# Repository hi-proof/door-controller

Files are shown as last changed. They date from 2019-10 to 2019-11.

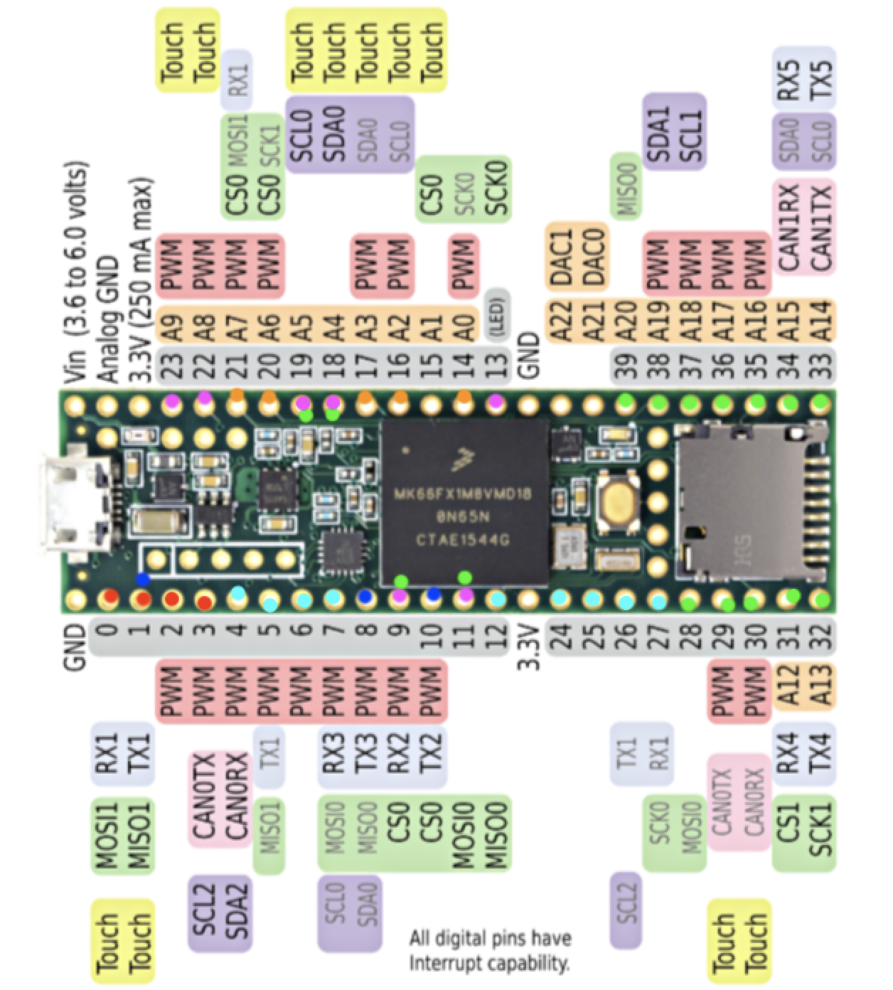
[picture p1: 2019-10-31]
pinout.png

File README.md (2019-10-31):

# Teensy 3.6 pinout

(see pinout.png)

* Red - b2b / serial (2 of the pins need to be serial TX/RX)
* Blue - LED ws2812 (pins need to be unused serial TX, should be limited to serial 1, 2, or 3)
* Pink - Audio - see audio shield docs. these can't be changed
* Orange - PWM
* Green - Door controllers
* Aqua - IO Panel

Notes:

1. 4 pins overlap between audio & door controller - those are for door controller D which can't be used at the same time as audio shield

2. Pin 15 is free and can be used for board id pull up / pull down

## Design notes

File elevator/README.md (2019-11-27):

Remember to change TeensyStep to use a different timer that doesn't conflict with PWM pins!!!

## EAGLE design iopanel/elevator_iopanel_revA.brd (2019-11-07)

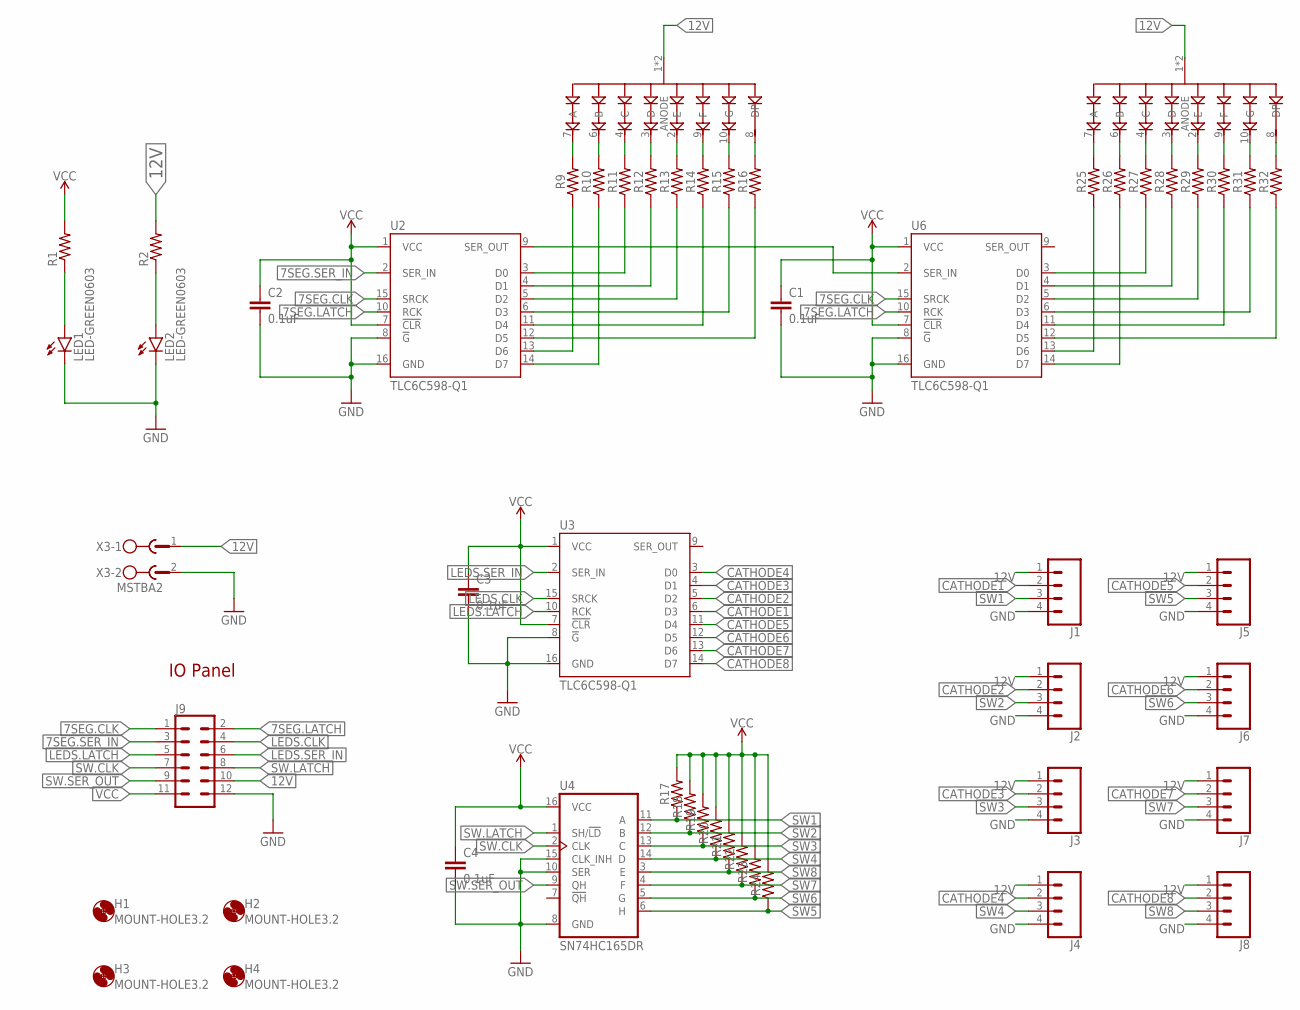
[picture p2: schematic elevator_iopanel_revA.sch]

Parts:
C1, C2, C3, C4: 0.1uF; 0603
D2, D4: SA15-11EWA
H1, H2, H3, H4: MOUNT-HOLE3.2; 3,2
J1, J2, J3, J4, J5, J6, J7, J8: CONN_04LONGPADS; 1X04_LONGPADS
J9: CONN_06X22X6SHR; 2X6-SHROUDED
LED1, LED2: LED-GREEN0603; 0603-GREEN
R1, R2: R-US_R0603; R0603
R9, R10, R11, R12, R13, R14, R15, R16, R17, R18, R19, R20, R21, R22, R23, R24, R25, R26, R27, R28, R29, R30, R31, R32: 20KOHM-0603-1/10W-1%; 0603
U2, U3, U6: TLC6C598-Q1; SO16
U4: SN74HC165DR; SO16
X3: MSTBA2

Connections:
7SEG.CLK: J9.1, U2.15 (SRCK), U6.15 (SRCK)
7SEG.LATCH: J9.2, U2.10 (RCK), U6.10 (RCK)
7SEG.SER_IN: J9.3, U2.2 (SER_IN)
12V: D2.1 (ANODE), D2.5 (ANODE), D4.1 (ANODE), D4.5 (ANODE), J1.1, J2.1, J3.1, J4.1, J5.1, J6.1, J7.1, J8.1, J9.10, R2.2, X3.1
A.SER_OUT: U2.9 (SER_OUT), U6.2 (SER_IN)
CATHODE1: J1.2, U3.6 (D3)
CATHODE2: J2.2, U3.5 (D2)
CATHODE3: J3.2, U3.4 (D1)
CATHODE4: J4.2, U3.3 (D0)
CATHODE5: J5.2, U3.11 (D4)
CATHODE6: J6.2, U3.12 (D5)
CATHODE7: J7.2, U3.13 (D6)
CATHODE8: J8.2, U3.14 (D7)
GND: C1.2, C2.2, C3.2, C4.2, J1.4, J2.4, J3.4, J4.4, J5.4, J6.4, J7.4, J8.4, J9.12, LED1.C, LED2.C, U2.8 (!G), U2.16 (GND), U3.8 (!G), U3.16 (GND), U4.8 (GND), U4.10 (SER), U4.15 (CLK_INH), U6.8 (!G), U6.16 (GND), X3.2
LEDS.CLK: J9.4, U3.15 (SRCK)
LEDS.LATCH: J9.5, U3.10 (RCK)
LEDS.SER_IN: J9.6, U3.2 (SER_IN)
unnamed: LED1.A, R1.1
unnamed: LED2.A, R2.1
unnamed: D2.7 (A), R9.2
unnamed: D2.6 (B), R10.2
unnamed: D2.4 (C), R11.2
unnamed: D2.3 (D), R12.2
unnamed: D2.2 (E), R13.2
unnamed: D2.9 (F), R14.2
unnamed: D2.10 (G), R15.2
unnamed: D2.8 (DP), R16.2
unnamed: R11.1, U2.3 (D0)
unnamed: R12.1, U2.4 (D1)
unnamed: R13.1, U2.5 (D2)
unnamed: R15.1, U2.6 (D3)
unnamed: R14.1, U2.11 (D4)
unnamed: R16.1, U2.12 (D5)
unnamed: R9.1, U2.13 (D6)
unnamed: R10.1, U2.14 (D7)
unnamed: D4.7 (A), R25.2
unnamed: D4.6 (B), R26.2
unnamed: D4.4 (C), R27.2
unnamed: D4.3 (D), R28.2
unnamed: D4.2 (E), R29.2
unnamed: D4.9 (F), R30.2
unnamed: D4.10 (G), R31.2
unnamed: D4.8 (DP), R32.2
unnamed: R27.1, U6.3 (D0)
unnamed: R28.1, U6.4 (D1)
unnamed: R29.1, U6.5 (D2)
unnamed: R31.1, U6.6 (D3)
unnamed: R30.1, U6.11 (D4)
unnamed: R32.1, U6.12 (D5)
unnamed: R25.1, U6.13 (D6)
unnamed: R26.1, U6.14 (D7)
SW1: J1.3, R17.1, U4.11 (A)
SW2: J2.3, R18.1, U4.12 (B)
SW3: J3.3, R19.1, U4.13 (C)
SW4: J4.3, R20.1, U4.14 (D)
SW5: J5.3, R24.1, U4.6 (H)
SW6: J6.3, R23.1, U4.5 (G)
SW7: J7.3, R22.1, U4.4 (F)
SW8: J8.3, R21.1, U4.3 (E)
SW.CLK: J9.7, U4.2 (CLK)
SW.LATCH: J9.8, U4.1 (SH/!LD)
SW.SER_OUT: J9.9, U4.9 (QH)
VCC: C1.1, C2.1, C3.1, C4.1, J9.11, R1.2, R17.2, R18.2, R19.2, R20.2, R21.2, R22.2, R23.2, R24.2, U2.1 (VCC), U2.7 (!CLR), U3.1 (VCC), U3.7 (!CLR), U4.16 (VCC), U6.1 (VCC), U6.7 (!CLR)

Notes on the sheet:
IO Panel

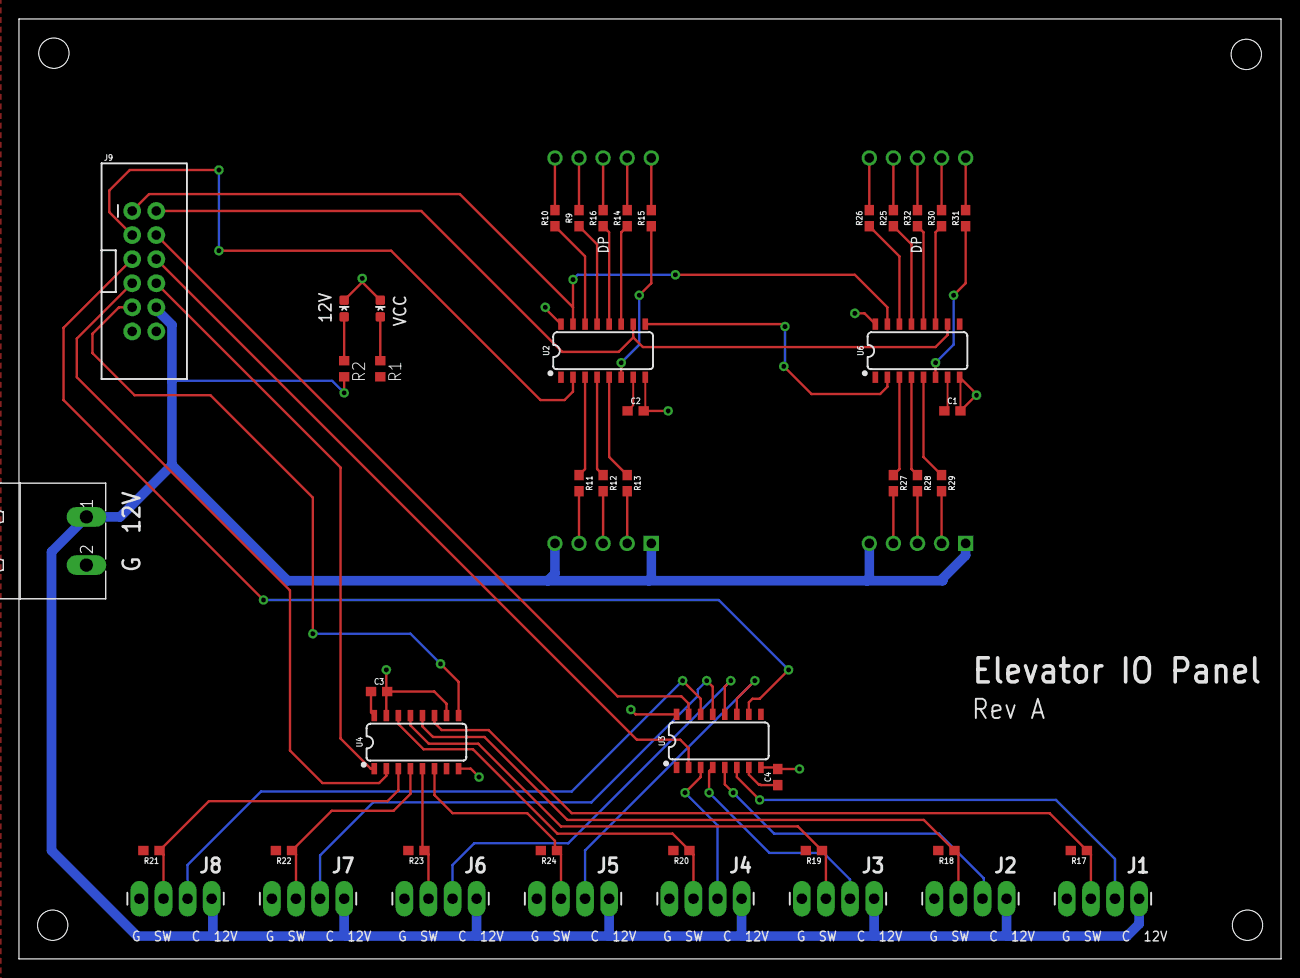
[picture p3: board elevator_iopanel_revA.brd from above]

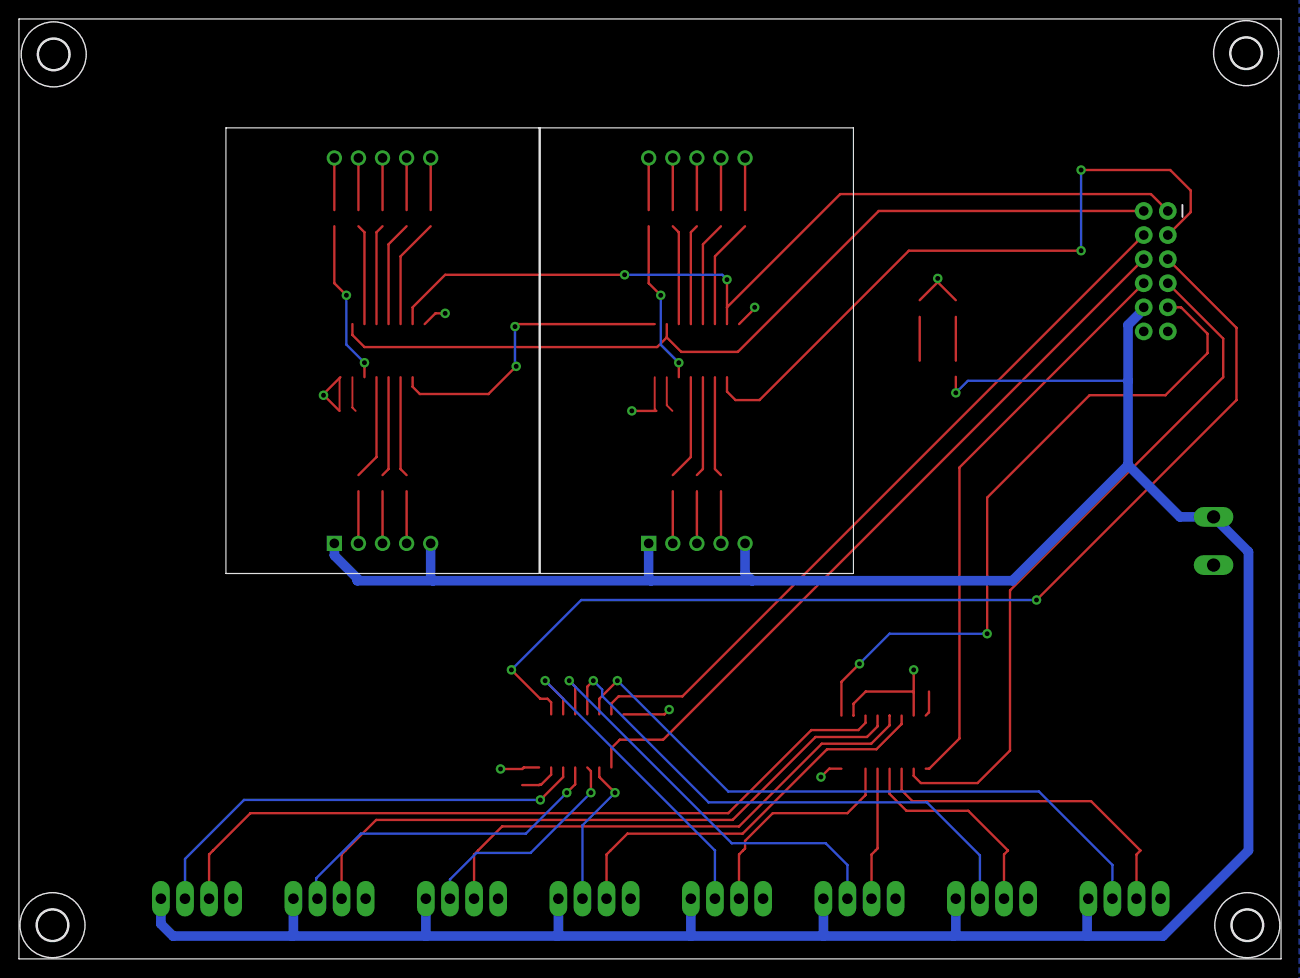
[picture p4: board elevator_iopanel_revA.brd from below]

Board: 2 copper layers, 133.1 x 99.1 mm, 52 parts (6 on the bottom side), 63 nets.

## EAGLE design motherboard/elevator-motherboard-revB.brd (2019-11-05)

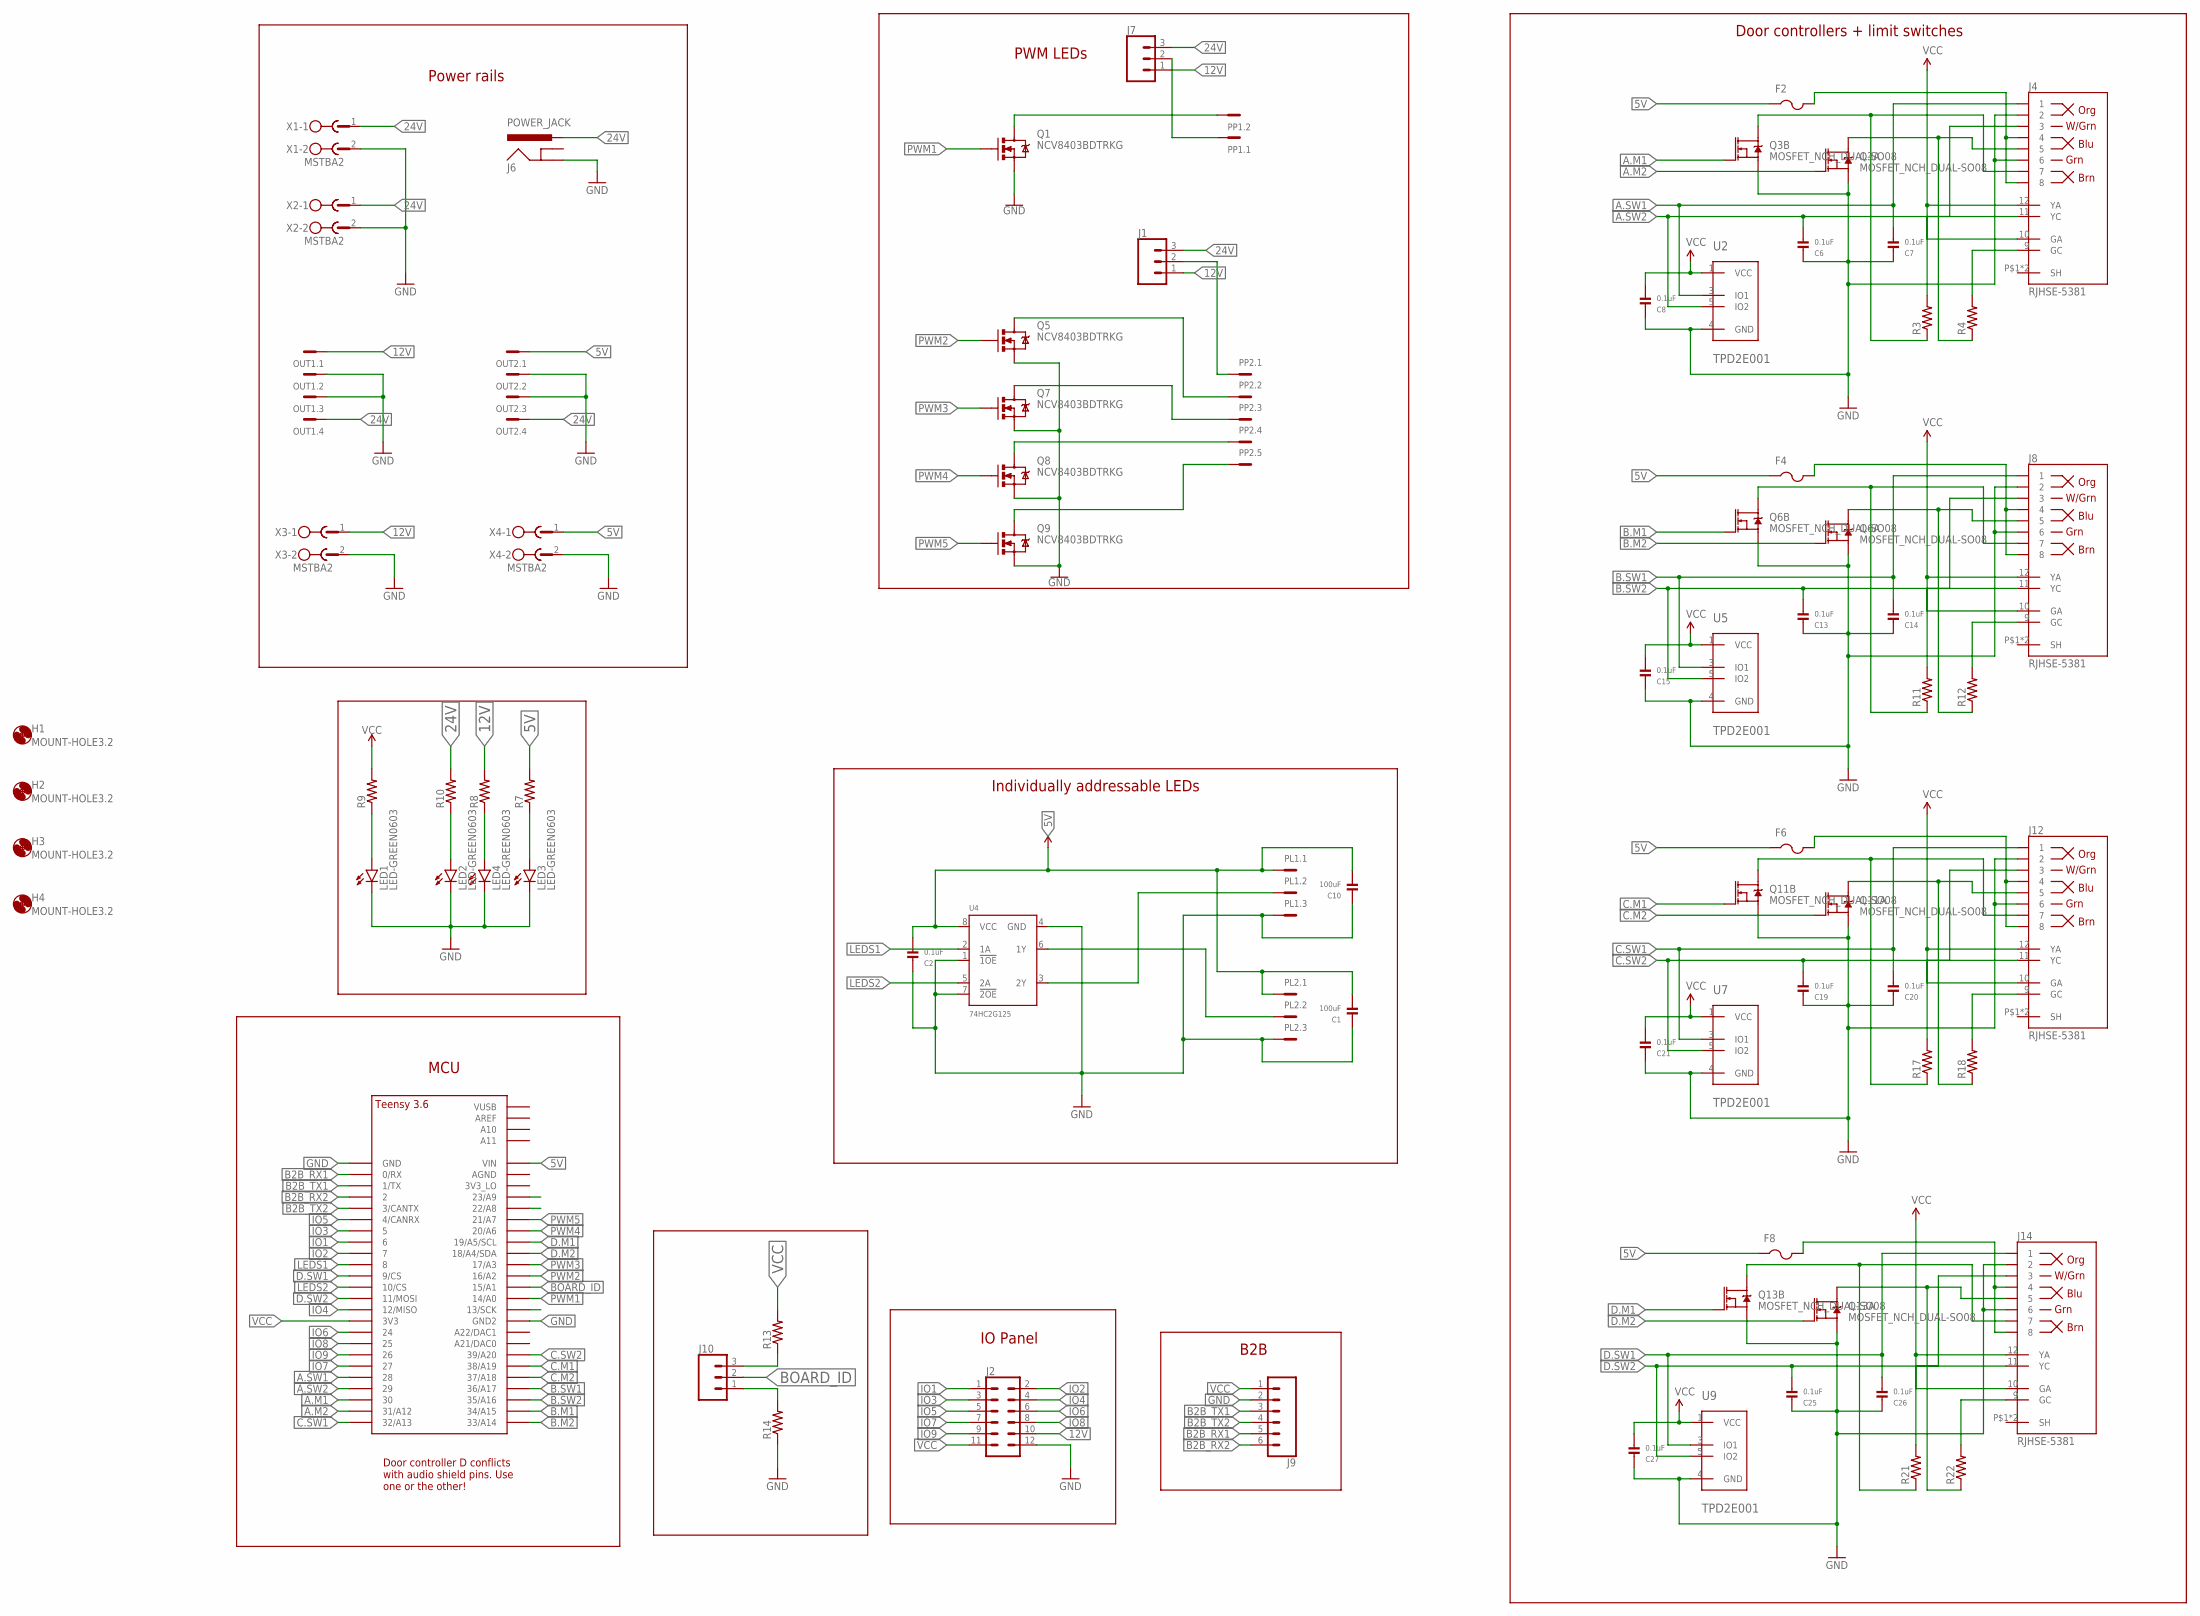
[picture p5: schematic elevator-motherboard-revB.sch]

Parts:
C1, C10: 100uF; 1206
C2, C6, C7, C8, C13, C14, C15, C19, C20, C21, C25, C26, C27: 0.1uF; 0603
F2, F4, F6, F8: PTCFUSE-1206; R1206
H1, H2, H3, H4: MOUNT-HOLE3.2; 3,2
J1, J7, J10: CONN_03; 1X03
J2: CONN_06X22X6SHR; 2X6-SHROUDED
J4, J8, J12, J14: RJHSE-5381; RJHSE-538X
J6: POWER_JACK; POWER_JACK_PTH
J9: CONN_06NO_SILK_FEMALE_PTH; 1X06_NO_SILK
LED1, LED2, LED3, LED4: LED-GREEN0603; 0603-GREEN
OUT1, OUT2: MC4
PL1, PL2: MC3
PP1: MC2
PP2: MC5
Q1, Q5, Q7, Q8, Q9: NCV8403BDTRKG; DPAK
Q3, Q6, Q11, Q13: MOSFET_NCH_DUAL-SO08; SO08
R3, R4, R7, R8, R9, R10, R11, R12, R13, R14, R17, R18, R21, R22: R-US_R0603; R0603
U2, U5, U7, U9: TPD2E001; SOT23-5L
U4: 74HC2G125; TSSOP8
U$1: TEENSY_3.5/3.6_BASIC
X1, X2, X3, X4: MSTBA2

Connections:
5V: C1.2, C2.2, C10.2, F2.1, F4.1, F6.1, F8.1, OUT2.1, PL1.1, PL2.1, R7.2, U4.8 (VCC), U$1.VIN, X4.1
12V: J1.1, J2.10, J7.1, OUT1.1, R8.2, X3.1
24V: J1.3, J6.PWR, J7.3, OUT1.4, OUT2.4, R10.2, X1.1, X2.1
A.M1: Q3.4 (G), U$1.30
A.M2: Q3.2 (G), U$1.31/A12
A.SW1: C7.2, J4.1, U2.3 (IO1), U$1.28
A.SW2: C6.2, J4.3, U2.5 (IO2), U$1.29
B2B_RX1: J9.5, U$1.0/RX
B2B_RX2: J9.6, U$1.2
B2B_TX1: J9.3, U$1.1/TX
B2B_TX2: J9.4, U$1.3/CANTX
B.M1: Q6.4 (G), U$1.34/A15
B.M2: Q6.2 (G), U$1.33/A14
B.SW1: C14.2, J8.1, U5.3 (IO1), U$1.36/A17
B.SW2: C13.2, J8.3, U5.5 (IO2), U$1.35/A16
BOARD_ID: J10.2, U$1.15/A1
C.M1: Q11.4 (G), U$1.38/A19
C.M2: Q11.2 (G), U$1.37/A18
C.SW1: C20.2, J12.1, U7.3 (IO1), U$1.32/A13
C.SW2: C19.2, J12.3, U7.5 (IO2), U$1.39/A20
D.M1: Q13.4 (G), U$1.19/A5/SCL
D.M2: Q13.2 (G), U$1.18/A4/SDA
D.SW1: C26.2, J14.1, U9.3 (IO1), U$1.9/CS
D.SW2: C25.2, J14.3, U9.5 (IO2), U$1.11/MOSI
GND: C1.1, C2.1, C6.1, C7.1, C8.1, C10.1, C13.1, C14.1, C15.1, C19.1, C20.1, C21.1, C25.1, C26.1, C27.1, J2.12, J4.2, J4.6, J6.GND, J8.2, J8.6, J9.2, J12.2, J12.6, J14.2, J14.6, LED1.C, LED2.C, LED3.C, LED4.C, OUT1.2, OUT1.3, OUT2.2, OUT2.3, PL1.3, PL2.3, Q1.3 (S), Q3.1 (S), Q3.3 (S), Q5.3 (S), Q6.1 (S), Q6.3 (S), Q7.3 (S), Q8.3 (S), Q9.3 (S), Q11.1 (S), Q11.3 (S), Q13.1 (S), Q13.3 (S), R14.1, U2.4 (GND), U4.1 (!1OE), U4.4 (GND), U4.7 (!2OE), U5.4 (GND), U7.4 (GND), U9.4 (GND), U$1.GND, U$1.GND2, X1.2, X2.2, X3.2, X4.2
IO1: J2.1, U$1.6
IO2: J2.2, U$1.7
IO3: J2.3, U$1.5
IO4: J2.4, U$1.12/MISO
IO5: J2.5, U$1.4/CANRX
IO6: J2.6, U$1.24
IO7: J2.7, U$1.27
IO8: J2.8, U$1.25
IO9: J2.9, U$1.26
LEDS1: U4.2 (1A), U$1.8
LEDS2: U4.5 (2A), U$1.10/CS
unnamed: PP1.2, Q1.4 (D)
unnamed: PL2.2, U4.6 (1Y)
unnamed: PL1.2, U4.3 (2Y)
unnamed: J4.7, Q3.5 (D), Q3.6 (D), R3.1
unnamed: J4.5, Q3.7 (D), Q3.8 (D), R4.1
unnamed: F2.2, J4.4, J4.8
unnamed: J4.11 (YC), R3.2
unnamed: PP2.2, Q5.4 (D)
unnamed: PP2.3, Q7.4 (D)
unnamed: PP2.4, Q8.4 (D)
unnamed: PP2.5, Q9.4 (D)
unnamed: J4.9 (GC), R4.2
unnamed: LED1.A, R9.1
unnamed: LED2.A, R10.1
unnamed: LED3.A, R7.1
unnamed: LED4.A, R8.1
unnamed: J10.3, R13.1
unnamed: J8.7, Q6.5 (D), Q6.6 (D), R11.1
unnamed: J8.5, Q6.7 (D), Q6.8 (D), R12.1
unnamed: F4.2, J8.4, J8.8
unnamed: J8.11 (YC), R11.2
unnamed: J8.9 (GC), R12.2
unnamed: J10.1, R14.2
unnamed: J7.2, PP1.1
unnamed: J1.2, PP2.1
unnamed: J12.7, Q11.5 (D), Q11.6 (D), R17.1
unnamed: J12.5, Q11.7 (D), Q11.8 (D), R18.1
unnamed: F6.2, J12.4, J12.8
unnamed: J12.11 (YC), R17.2
unnamed: J12.9 (GC), R18.2
unnamed: J14.7, Q13.5 (D), Q13.6 (D), R21.1
unnamed: J14.5, Q13.7 (D), Q13.8 (D), R22.1
unnamed: F8.2, J14.4, J14.8
unnamed: J14.11 (YC), R21.2
unnamed: J14.9 (GC), R22.2
PWM1: Q1.1 (G), U$1.14/A0
PWM2: Q5.1 (G), U$1.16/A2
PWM3: Q7.1 (G), U$1.17/A3
PWM4: Q8.1 (G), U$1.20/A6
PWM5: Q9.1 (G), U$1.21/A7
VCC: C8.2, C15.2, C21.2, C27.2, J2.11, J4.10 (GA), J4.12 (YA), J8.10 (GA), J8.12 (YA), J9.1, J12.10 (GA), J12.12 (YA), J14.10 (GA), J14.12 (YA), R9.2, R13.2, U2.1 (VCC), U5.1 (VCC), U7.1 (VCC), U9.1 (VCC), U$1.3V3

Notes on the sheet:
Door controller D conflicts with audio shield pins. Use one or the other!
Power rails
MCU
PWM LEDs
Individually addressable LEDs
IO Panel
B2B
Door controllers + limit switches

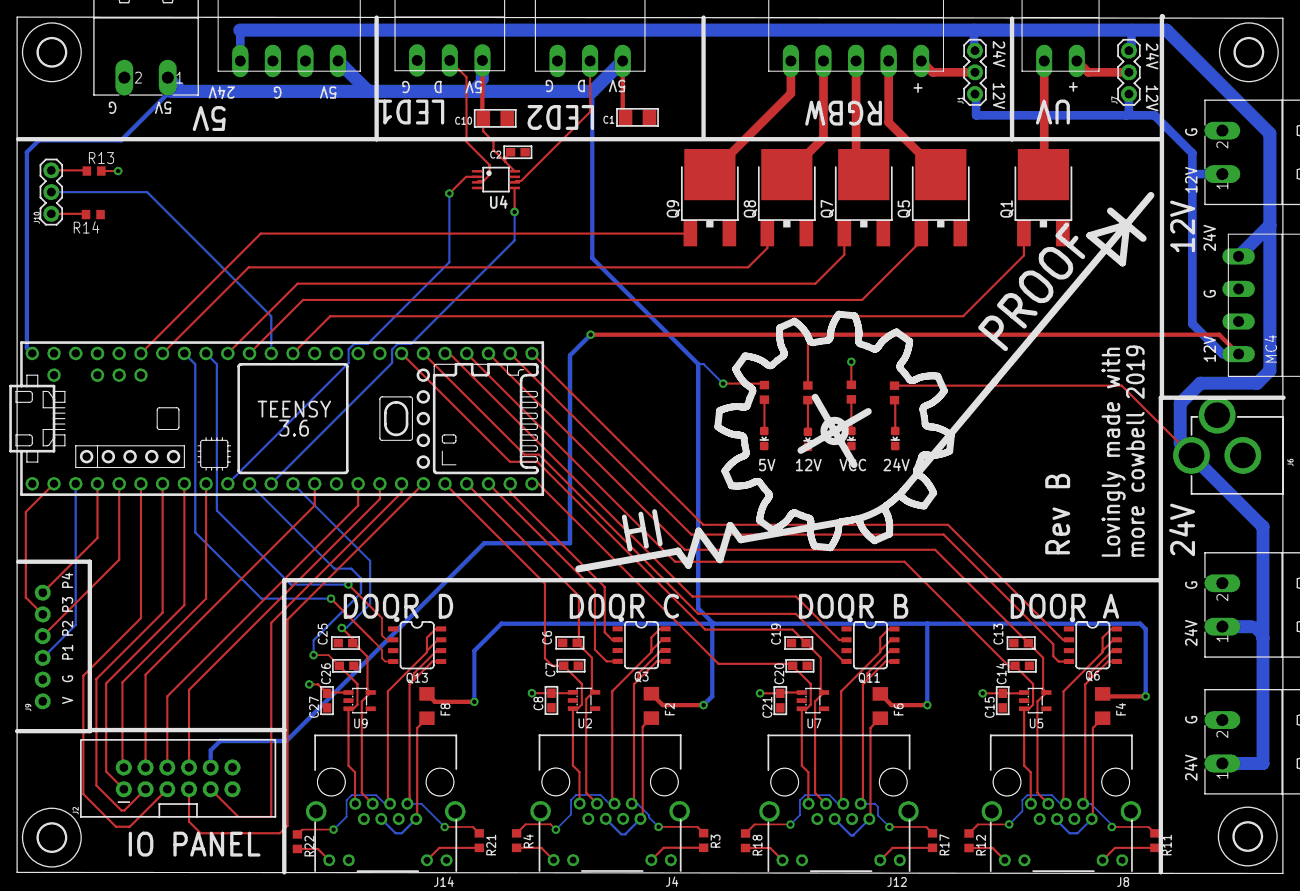
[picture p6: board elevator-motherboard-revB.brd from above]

Board: 2 copper layers, 148.0 x 100.1 mm, 76 parts (0 on the bottom side), 77 nets.

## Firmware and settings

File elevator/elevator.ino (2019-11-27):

#include <PacketSerial.h>
#include <TeensyStep.h>
#include <Shell.h>
#include <Bounce2.h>
#include <FastLED.h>
#include <SD.h>
#include <Audio.h>
#include <EEPROM.h>
#include <FastLED.h>

#include "pins.h"
#include "parallelio.h"
#include "state.h"
#include "controllers.h"
#include "AudioSampleDing.h"

//--------------------------------------------------------------------------


#include <Audio.h>
#include <Wire.h>
#include <SPI.h>
#include <SD.h>
#include <SerialFlash.h>

// GUItool: begin automatically generated code
AudioPlaySdRaw           playBackground1; //xy=246,298
AudioPlaySdRaw           playBackground2;     //xy=247,339
AudioPlaySdRaw           playBackground3;     //xy=247,379
AudioPlayMemory          playDings;      //xy=256,229
AudioMixer4              mixerTop;       //xy=516,310
AudioMixer4              mixerBottom;    //xy=518,396
AudioOutputI2S           i2s1;           //xy=704,312
//AudioOutputUSB           usb1;           //xy=704,384
AudioConnection          patchCord1(playBackground1, 0, mixerTop, 1);
AudioConnection          patchCord2(playBackground1, 0, mixerBottom, 1);
AudioConnection          patchCord3(playBackground2, 0, mixerTop, 2);
AudioConnection          patchCord4(playBackground2, 0, mixerBottom, 2);
AudioConnection          patchCord5(playBackground3, 0, mixerBottom, 3);
AudioConnection          patchCord6(playBackground3, 0, mixerTop, 3);
AudioConnection          patchCord7(playDings, 0, mixerTop, 0);
AudioConnection          patchCord8(playDings, 0, mixerBottom, 0);
AudioConnection          patchCord9(mixerTop, 0, i2s1, 0);
//AudioConnection          patchCord10(mixerTop, 0, usb1, 0);
AudioConnection          patchCord11(mixerBottom, 0, i2s1, 1);
//AudioConnection          patchCord12(mixerBottom, 0, usb1, 1);
AudioControlSGTL5000     sgtl5000_1;     //xy=528,191
// GUItool: end automatically generated code

//--------------------------------------------------------------------------


WS2812Serial *pserial;
uint8_t *drawbuffer,*framebuffer;

void init_leds(int nLeds) {
  if (pserial == NULL) {
    drawbuffer = (uint8_t*)malloc(nLeds * 3);
    framebuffer = (uint8_t*)malloc(nLeds * 12);
    pserial = new WS2812Serial(nLeds, framebuffer, drawbuffer, DATA_PIN, WS2812_RGB);
    pserial->begin();
  }
}

PacketSerial b2b_comms;
uint32_t last_tx;
uint32_t last_rx;

inner_state_t inner_state;
outer_state_t outer_state;

bool is_outer;
uint8_t av_mode = AV_LOBBY;

void tx_msg(uint8_t msg, uint8_t * buffer, uint8_t size) {
  static uint8_t msg_buffer[255];
  if (size > 254) {
    size = 254;
  }
  msg_buffer[0] = msg;
  memcpy(&msg_buffer[1], buffer, size);
  b2b_comms.send(msg_buffer, size + 1);
}

//--------------------------------------------------------------------------
// Globals and functions shared between inner and outer MCUs


class Elevator
{
  public:
    Floor susan;
    Door d1;
    Door d2;
    bool with_floor;
    RotateControl rc;

    uint8_t mode;
    uint8_t doors_state;
    uint8_t floor_state;

    uint8_t pending_dest_id;
    uint8_t destination_id;
    int32_t destination_pos;
    int32_t origin_pos;

    int32_t positions[LOCATION_COUNT];

    bool goto_pending;
    bool just_arrived;
    bool just_started;
    bool call_button_pressed;

    bool force_state_update;

    Elevator(bool with_floor = false)
      : rc(25),
        susan(34, 33, 36, 35, rc), // port A
        d1(38, 37, 39, 32, rc),    // port B
        d2(30, 31, 28, 29, rc),    // port C
        with_floor(with_floor),
        doors_state(DOOR_NOT_CALIBRATED),
        mode(MODE_NOT_CALIBRATED),
        floor_state(FLOOR_NOT_CALIBRATED),
        call_button_pressed(false)
    {
      positions[LOCATION_LOBBY] = load_location(LOCATION_LOBBY);
      positions[LOCATION_13F] = load_location(LOCATION_13F);
      positions[LOCATION_14F] = load_location(LOCATION_14F);
    }

    int32_t load_location(uint8_t location_id) {
      int32_t ret;
      EEPROM.get(location_id * sizeof(int32_t), ret);
      return ret;
    }

    int32_t save_location(uint8_t location_id, int32_t position) {
      shell_printf("Saving location %d at %d\r\n", location_id, position);
      positions[location_id] = position;
      EEPROM.put(location_id * sizeof(int32_t), position);
    }

    bool calibrated()
    {
      bool ret = d1.calibrated && d2.calibrated;
      if (with_floor) {
        ret &= susan.calibrated;
      }
      return ret;
    }

    void set_mode(uint8_t new_mode) {
      shell_printf("Setting elevator mode to: %d\r\n", new_mode);
      mode = new_mode;
      call_button_pressed = false;
      force_state_update = true;
      switch (new_mode) {
        case MODE_MAINTENANCE:
          susan.stop(true);
          destination_id = 100;
          open();
          tx_msg(MSG_OPEN, NULL, 0);
          break;

        case MODE_ONLINE:
          susan.stop(true);
          break;

        case MODE_OFFLINE:
          susan.stop(true);
          goto_destination(LOCATION_LOBBY);
          open();
          tx_msg(MSG_OPEN, NULL, 0);
          break;
      }
    }

    // hella blocking
    void calibrate()
    {
      shell_printf("Starting elevator calibration\r\n");
      
      d1.calibrate();
      d1.goto_pos(0);
      
      d2.calibrate();
      d2.goto_pos(0);
      
      doors_state = DOOR_OPEN;
      if (with_floor) {
        shell_printf("Calibrating floor\r\n");
        susan.calibrate();
        floor_state = FLOOR_STATIONARY;
        destination_id = LOCATION_LOBBY;
        destination_pos = 0;
        origin_pos = 0;
      }
      mode = MODE_ONLINE;
      shell_printf("Elevator calibrated\r\n");
    }

    // blocking if doors are already moving
    void doors(bool open) {
      if (!calibrated()) {
        shell_printf("ERROR tried using doors before calibration\r\n");
        return;
      }

      if (open && doors_state == DOOR_OPENING || !open && doors_state == DOOR_CLOSING) {
        return;
      }

      if (open) {
        doors_state = DOOR_OPENING;
        d1.open();
        d2.open();
      } else {
        doors_state = DOOR_CLOSING;
        d1.close();
        d2.close();
      }
    }

    void open() {
      doors(true);
    }

    void close() {
      doors(false);
    }

    void goto_destination(uint8_t destination_id) {
      // for now - ignore we aren't stationary
      if (floor_state != FLOOR_STATIONARY) {
        shell_printf("Wait for elevator to stop before moving\r\n");
        return;
      }

      // already there?
      if (destination_id == this->destination_id) {
        return;
      }

      this->pending_dest_id = destination_id;
      this->destination_pos = positions[destination_id];
      this->origin_pos = susan.s.getPosition();

      shell_printf("Going to destination id %d position %d (current position %d)\r\n", destination_id, destination_pos, origin_pos);

      this->goto_pending = true;
      tx_msg(MSG_CLOSE, NULL, 0);
      close();
    }

    void update()
    {
      d1.update();
      d2.update();
      susan.update();
      force_state_update = false;
      if (doors_state == DOOR_OPENING) {
        if (!d1.sc.isRunning() & !d2.sc.isRunning()) {
          doors_state = DOOR_OPEN;
          force_state_update = true;
        }
      }

      if (doors_state == DOOR_CLOSING) {
        if (!d1.sc.isRunning() & !d2.sc.isRunning()) {
          doors_state = DOOR_CLOSED;
          force_state_update = true;
        }
      }

      just_arrived = false;
      just_started = false;

      if (with_floor) {
        if (floor_state == FLOOR_STATIONARY && mode == MODE_ONLINE && goto_pending) {
          if ((doors_state == DOOR_CLOSED) && (inner_state.door_state == DOOR_CLOSED)) {
            destination_id = pending_dest_id;
            floor_state = FLOOR_MOVING;
            susan.goto_pos(destination_pos);
            goto_pending = false;
            just_started = true;
          }
        } else if (floor_state == FLOOR_MOVING) {
          if (!susan.sc.isRunning()) {
            floor_state = FLOOR_STATIONARY;
            just_arrived = true;
          }
        }
      }
    }
};

Elevator elevator(false);

//--------------------------------------------------------------------------
// OUTER CONTROLLER

void on_rx_button_event(event_button_t * evt)
{
  uint8_t event_id = (evt->button & 0xF0) >> 4;
  uint8_t button_id = (evt->button & 0x0F);
  
  switch (elevator.mode) {
    case MODE_NOT_CALIBRATED:
      if (button_id == BTN_BELL && event_id == BTN_HOLD) {
        tx_msg(MSG_HOME, NULL, 0);
        delay(50);
        elevator.calibrate();
      }
      break;

    case MODE_MAINTENANCE:
      if (button_id == BTN_BELL && event_id == BTN_HOLD) {
        elevator.set_mode(MODE_ONLINE);
      }
      if (button_id == BTN_BELL && event_id == BTN_CLICK) {
        elevator.susan.stop(true);
      }
      if (button_id == BTN_OPEN && event_id == BTN_CLICK) {
        elevator.susan.rotate(true);
      }
      if (button_id == BTN_CLOSE && event_id == BTN_CLICK) {
        elevator.susan.rotate(false);
      }
      if (button_id == BTN_STAR && event_id == BTN_HOLD) {
        elevator.save_location(LOCATION_LOBBY, elevator.susan.s.getPosition());
        tx_msg(MSG_DING, NULL, 0);
      }
      if (button_id == BTN_13 && event_id == BTN_HOLD) {
        elevator.save_location(LOCATION_13F, elevator.susan.s.getPosition());
        tx_msg(MSG_DING, NULL, 0);
      }
      if (button_id == BTN_14 && event_id == BTN_HOLD) {
        elevator.save_location(LOCATION_14F, elevator.susan.s.getPosition());
        tx_msg(MSG_DING, NULL, 0);
      }
      break;

    case MODE_ONLINE:
      if (button_id == BTN_BELL && event_id == BTN_PRESS) {
        tx_msg(MSG_DING, NULL, 0);
      }
      if (button_id == BTN_BELL && event_id == BTN_HOLD) {
        if ((evt->all_buttons & (1 << BTN_STAR)) && (evt->all_buttons & (1 << BTN_13)) && (evt->all_buttons & (1 << BTN_14))) {
          elevator.set_mode(MODE_MAINTENANCE);
        }
        else if ((evt->all_buttons & (1 << BTN_CLOSE)) && (evt->all_buttons & (1 << BTN_OPEN))) {
          tx_msg(MSG_HOME, NULL, 0);
          delay(100);
          elevator.calibrate();
        }
        else if (evt->all_buttons & (1 << BTN_OPEN)) {
          elevator.set_mode(MODE_OFFLINE);
        }
      }
      if (button_id == BTN_STAR && event_id == BTN_CLICK) {
        elevator.goto_destination(LOCATION_LOBBY);
      }
      if (button_id == BTN_13 && event_id == BTN_CLICK) {
        elevator.goto_destination(LOCATION_13F);
      }
      if (button_id == BTN_14 && event_id == BTN_CLICK) {
        elevator.goto_destination(LOCATION_14F);
      }
      if (button_id == BTN_OPEN && event_id == BTN_PRESS) {
        if (elevator.floor_state == FLOOR_STATIONARY) {
          tx_msg(MSG_OPEN, NULL, 0);
          if (elevator.destination_id == LOCATION_LOBBY) {
            elevator.open();
          }
        }
      }
      if (button_id == BTN_CLOSE && event_id == BTN_PRESS) {
        if (elevator.floor_state == FLOOR_STATIONARY) {
          tx_msg(MSG_CLOSE, NULL, 0);
          if (elevator.destination_id == LOCATION_LOBBY) {
            elevator.close();
          }
        }
      }

      break;

    case MODE_OFFLINE:
      if (button_id == BTN_BELL && event_id == BTN_HOLD) {
        if ((evt->all_buttons & (1 << BTN_STAR)) && (evt->all_buttons & (1 << BTN_OPEN))) {
          elevator.set_mode(MODE_ONLINE);
        }
      }

      if (button_id == BTN_BELL && event_id == BTN_PRESS) {
        tx_msg(MSG_DING, NULL, 0);
      }

      if (button_id == BTN_CLOSE && event_id == BTN_PRESS) {
        av_mode = (av_mode + 1) % AV_MODES_COUNT;
        tx_msg(MSG_AVMODE, (uint8_t*)&av_mode, 1);
      }
      if (button_id == BTN_OPEN && event_id == BTN_PRESS) {
        av_mode = (av_mode - 1) % AV_MODES_COUNT;
        tx_msg(MSG_AVMODE, (uint8_t*)&av_mode, 1);
      }

      break;

  }
}

void on_rx_outer(const uint8_t* buffer, size_t size)
{
  switch (buffer[0]) {
    case MSG_INNER_STATE:
      memcpy(&inner_state, &buffer[1], sizeof(inner_state));
      break;

    case MSG_EVENT_BUTTON:
      on_rx_button_event((event_button_t *)&buffer[1]);
      break;

    case MSG_EVENT_DOOR:
      // door state changed. do somtin about it

      break;
  }
}


//--------------------------------------------------------------------------
// INNER CONTROLLER

float lerp(float a, float b, float x)
{
  return a + x * (b - a);
}

constexpr int NUM_BACKGROUND_TRACKS = 3;
float background_volumes[NUM_BACKGROUND_TRACKS] = {0};

struct Transitions {
  float source_volumes[NUM_BACKGROUND_TRACKS];
  float dest_volumes[NUM_BACKGROUND_TRACKS];
  int32_t start_time;
  int32_t duration;

  Transitions() :
    source_volumes( {
    0
  }), dest_volumes({1, 0, 0}), start_time(0), duration(1) {

  }

  void start_transition(uint8_t target_floor) {
    // copy current audio state as start
    memcpy(source_volumes, background_volumes, sizeof(source_volumes));
    memset(dest_volumes, 0, sizeof(dest_volumes));
    dest_volumes[target_floor] = 1.;

    start_time = millis();
    // TODO: vary according to target/source
    duration = 3000;
  }

  void update() {
    float relative_time = (millis() - start_time) / (float)duration;
    if ((relative_time >= 0) && (relative_time <= 1.)) {
      for (int i = 0; i < NUM_BACKGROUND_TRACKS; i++) {
        background_volumes[i] = lerp(source_volumes[i], dest_volumes[i], relative_time);
      }
      //      shell_printf("rel time: %d, bv: %d %d %d\r\n",
      //                    (int)(relative_time * 100),
      //                    (int)(background_volumes[0]*100),
      //                    (int)(background_volumes[1]*100),
      //                    (int)(background_volumes[2]*100));
    } else {
      memcpy(background_volumes, dest_volumes, sizeof(background_volumes));
    }

    for (int i = 0; i < NUM_BACKGROUND_TRACKS; i++) {
      // TODO: up/down motion via panning between top and bottom
      mixerTop.gain(i + 1, background_volumes[i]);
      mixerBottom.gain(i + 1, background_volumes[i]);
    }

    if (background_volumes[0] > 0.02 && !playBackground1.isPlaying()) {
      playBackground1.play("LEVEL12.RAW");
    } else if (background_volumes[0] < 0.02 && playBackground1.isPlaying()) {
      playBackground1.stop();
    }

    if (background_volumes[1] > 0.02 && !playBackground2.isPlaying()) {
      playBackground2.play("LEVEL13.RAW");
    } else if (background_volumes[1] < 0.02 && playBackground2.isPlaying()) {
      playBackground2.stop();
    }

    if (background_volumes[2] > 0.02 && !playBackground3.isPlaying()) {
      playBackground3.play("LEVEL14.RAW");
    } else if (background_volumes[2] < 0.02 && playBackground3.isPlaying()) {
      playBackground3.stop();
    }
  }
};

Transitions transitions;

void on_rx_inner(const uint8_t* buffer, size_t size)
{
  switch (buffer[0]) {
    case MSG_OUTER_STATE: {
        outer_state_t * new_state = (outer_state_t *)&buffer[1];
        elevator.mode = new_state->system_mode;
        elevator.call_button_pressed = new_state->flags & (1 << FLAG_CALL_BUTTON_PENDING);
        elevator.goto_pending = new_state->flags & (1 << FLAG_GOTO_PENDING);
        elevator.destination_id = new_state->destination;
        elevator.floor_state = new_state->floor_state;
      }
      break;
    case MSG_OPEN:
      elevator.open();
      break;

    case MSG_CLOSE:
      elevator.close();
      break;

    case MSG_HOME:
      // blocking
      elevator.calibrate();
      break;

    case MSG_UI_OVERRIDE: break;

    case MSG_TRIGGER_TRANSITION:
      // start transition to target floor
      transitions.start_transition(buffer[1]);
      switch (buffer[1]) {
        case LOCATION_LOBBY:
          av_mode = AV_LOBBY;
          break;
        case LOCATION_13F:
          av_mode = AV_LAB;
          break;
        case LOCATION_14F:
          av_mode = AV_SPACE;
          break;
      }
      break;

    case MSG_DING:
      playDings.play(AudioSampleDing);
      break;

    case MSG_AVMODE:
      av_mode = buffer[1];
      break;
  }
}


//--------------------------------------------------------------------------
// SHARED PROCESSING, Setup, loop, etc


void on_rx(const uint8_t* buffer, size_t size)
{
  last_rx = millis();
  if (is_outer) {
    on_rx_outer(buffer, size);
  } else {
    on_rx_inner(buffer, size);
  }
}

void setup() {
  // board id
  pinMode(PIN_BOARD_ID, INPUT);
  is_outer = digitalRead(PIN_BOARD_ID) == HIGH;

  elevator.with_floor = is_outer;

  // b2b comms
  Serial1.begin(9600);
  b2b_comms.setStream(&Serial1);
  b2b_comms.setPacketHandler(on_rx);

  // USB serial for debug
  Serial.begin(9600);
  //while (!Serial);
  shell_init(shell_reader, shell_writer, PSTR("Hi-Proof elevatormatic"));

  // LED indicator on teensy
  pinMode(PIN_TEENSY_LED, OUTPUT);
  digitalWrite(PIN_TEENSY_LED, HIGH);

  pinMode(PIN_UV, OUTPUT);
  digitalWrite(PIN_UV, LOW);

  shell_register(command_info, PSTR("i"));
  shell_register(command_home, PSTR("home"));
  shell_register(command_test, PSTR("test"));
  shell_register(command_open, PSTR("open"));
  shell_register(command_close, PSTR("close"));

  if (!is_outer) {
    AudioMemory(100);
    shell_printf("Opening SD...");
    if (!SD.begin(BUILTIN_SDCARD)) {
      shell_printf("Error opening SD\r\n");
    } else {
      shell_printf("Done\r\n");
    }
  
    sgtl5000_1.enable();
    sgtl5000_1.volume(1.0);
  
    mixerTop.gain(0, 1.0);
    mixerTop.gain(1, 1.0);
    mixerTop.gain(2, 1.0);
    mixerTop.gain(3, 1.0);
  
    mixerBottom.gain(0, 1.0);
    mixerBottom.gain(1, 1.0);
    mixerBottom.gain(2, 1.0);
    mixerBottom.gain(3, 1.0);


    LEDS.addLeds<WS2812SERIAL>(leds, NUM_LEDS_PER_STRIP)
    
  }
}
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
void loop() {
  // update inputs
  buttons.update();
  b2b_comms.update();
  panel.update_inputs();


  // process
  shell_task();
  elevator.update();

  if (is_outer) {
    process_outer();
  } else {
    process_inner();
  }

  //UI
  do_ui();
  
  // update outputs
  panel.update_outputs();
  button_leds.update();
  sseg.update();

  //  // send state if enough time passed
  if ((millis() - last_tx > 2000) || elevator.force_state_update) {
    //command_info(0, NULL);
    if (is_outer) {
      tx_msg(MSG_OUTER_STATE, (uint8_t*)&outer_state, sizeof(outer_state));
    } else {
      tx_msg(MSG_INNER_STATE, (uint8_t*)&inner_state, sizeof(inner_state));
    }
    last_tx = millis();
  }
}

//-------------------------------------------------------------------------------------------
// CLI commands

int command_info(int argc, char ** argv)
{
  bool outer = digitalRead(15) == HIGH;
  shell_printf("Board id: %s\r\n", outer ? "OUTER" : "INNER");
  shell_printf("F: %d %d %s   D1: %d %s   D2: %d %s  D: %d\r\n",
               elevator.floor_state,
               elevator.susan.s.getPosition(), elevator.susan.sc.isRunning() ? "RUNNING" : "IDLE",
               elevator.d1.s.getPosition(), elevator.d1.sc.isRunning() ? "RUNNING" : "IDLE",
               elevator.d2.s.getPosition(), elevator.d2.sc.isRunning() ? "RUNNING" : "IDLE",
               elevator.doors_state);
  shell_printf("F SW1: %d  S2: %d\r\n", 
    elevator.susan.sw1_hit(),  elevator.susan.sw2_hit());
  return SHELL_RET_SUCCESS;
}

int command_open(int argc, char ** argv)
{
  elevator.doors(true);
  return SHELL_RET_SUCCESS;
}

int command_close(int argc, char ** argv)
{
  elevator.doors(false);
  return SHELL_RET_SUCCESS;
}


int command_home(int argc, char ** argv)
{
  tx_msg(MSG_HOME, NULL, 0);
  delay(50);
  elevator.calibrate();
  return SHELL_RET_SUCCESS;
}

int command_test(int argc, char ** argv)
{
//  elevator.susan.rotate(true);
//  delay(1000);
  //playBackground1.play("LEVEL0.RAW");
  //elevator.goto_destination(LOCATION_13F);
  // test ding
//  uint8_t msg = MSG_DING;
//  on_rx_inner(&msg, sizeof(msg));
  // test audio transitions
  //  static int index = 0;
  //  transitions.start_transition(index % 3);
  //  index++;
  // test transition detection
  //  switch(index){
  //    case 0:
  //      elevator.goto_destination(LOCATION_13F);
  //      break;
  //    case 1:
  //      elevator.goto_destination(LOCATION_14F);
  //      break;
  //    case 2:
  //      elevator.goto_destination(LOCATION_13F);
  //      break;
  //    case 3:
  //      elevator.goto_destination(LOCATION_LOBBY);
  //      break;
  //    case 4:
  //      elevator.goto_destination(LOCATION_14F);
  //      break;
  //    case 5:
  //      elevator.goto_destination(LOCATION_LOBBY);
  //      break;
  //  }
  //  index = (index + 1) % 6;


  //playBackground.play("LEVEL0.RAW");
  //  elevator.calibrate();
  //  elevator.susan.rotate(true);

  //elevator.susan.rotate(true);
  //  delay(1000);
  //  elevator.susan.stop();
  //  elevator.susan.rotate(false);
  //  delay(1000);
  //  elevator.susan.stop();
  return SHELL_RET_SUCCESS;
}


//-------------------------------------------------------------------------------------------
// CLI boilerplate

int shell_reader(char * data)
{
  // Wrapper for Serial.read() method
  if (Serial.available()) {
    *data = Serial.read();
    return 1;
  }
  return 0;
}

void shell_writer(char data)
{
  // Wrapper for Serial.write() method
  Serial.write(data);
}

//////////////////// network code /////////////////////

enum packet_type {
  ELEVATOR_TO_OUTSIDE = 0,
  SCREEN_UPDATE,
  PACKET_TYPES
};

void update_screen(const struct screen_update_packet_t * screen_update) {
  sseg.values[0] = SSeg::digit(screen_update->digit_1);
  sseg.values[1] = SSeg::digit(screen_update->digit_2);
}

void onPacketReceived(const uint8_t* buffer, size_t size)
{
    switch((packet_type)buffer[0]) {
      case ELEVATOR_TO_OUTSIDE:
        // TODO: compare current state to previous state, see if we need to get motor running etc.
        //
        // resolve_state((elevator_to_outside_packet_t *)buffer);
        break;
      case SCREEN_UPDATE:
        update_screen((const screen_update_packet_t *)buffer);
    }
}

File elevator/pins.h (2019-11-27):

#pragma once

#define SW_DATA (26)
#define SW_CLOCK (27)
#define SW_LATCH (25)

#define BL_DATA   (24)
#define BL_CLOCK  (12)
#define BL_LATCH  (4)

#define SSEG_DATA (5)
#define SSEG_CLOCK (6)
#define SSEG_LATCH (7) 

enum {
  PIN_BOARD_ID = 15,
  PIN_TEENSY_LED = 13,

  PIN_UV = 14,
  PIN_R = 17,
  PIN_G = 16,
  PIN_B = 20,
  PIN_W = 21,
};

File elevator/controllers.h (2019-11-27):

#pragma once

#include <TeensyStep.h>

const uint32_t HOMING_SPEED = 500;
const uint32_t HOMING_ACCEL = 500;

const uint32_t DOOR_SPEED = 5000;
const uint32_t DOOR_ACCEL = 1500;

const uint32_t FLOOR_SPEED = 1800;
const uint32_t FLOOR_ACCEL = 700;

enum {
  MOTOR_STOPPED,
  MOTOR_STOPPING,
  MOTOR_ROTATING,
  MOTOR_GOINGTO,  
};

class MotorAndSwitches
{
  public:

    uint8_t pin_dir, pin_pulse, pin_sw1, pin_sw2;

    int homing_speed;
    int homing_accel;

    int motor_speed;
    int motor_accel;

    // This is SUPER ghetto - we have 8 available timer channels and each control uses 2, so we're
    // limited to 4 controls system-wide. We'll have 3 StepControls for Door, Door, and Floor, and a
    // a shared RotateControl that will be used for calibration
    StepControl sc;
    RotateControl& rc;
    Stepper s;

    int32_t pending_pos;
    bool pending_goto;

    uint8_t stop_sw;

    MotorAndSwitches(uint8_t pin_pulse, uint8_t pin_dir, uint8_t pin_sw1, uint8_t pin_sw2, RotateControl& rc)
      : s(pin_pulse, pin_dir), sc(25), rc(rc),
        homing_speed(HOMING_SPEED), homing_accel(HOMING_ACCEL),
        pending_goto(false)
    {
      this->pin_dir = pin_dir;
      this->pin_pulse = pin_pulse;
      this->pin_sw1 = pin_sw1;
      this->pin_sw2 = pin_sw2;

      pinMode(this->pin_sw1, INPUT_PULLUP);
      pinMode(this->pin_sw2, INPUT_PULLUP);
    }

    bool sw1_hit()
    {
      return digitalRead(this->pin_sw1) == HIGH;
    }

    bool sw2_hit()
    {
      return digitalRead(this->pin_sw2) == HIGH;
    }

    // async
    void rotate(bool dir, int speed=0, int accel=0) 
    {
      if (speed == 0) {
        speed = motor_speed;
      }
      if (accel == 0) {
        accel = motor_accel;
      }
      
      stop(true);
      stop_sw = (dir) ? pin_sw2 : pin_sw1; 
      s.setMaxSpeed(dir ? speed : -speed);
      s.setAcceleration(accel);
      rc.rotateAsync(s);
    }

    void stop(bool sync=false)
    {
      if (sync) {
        rc.stop();
        sc.stop();
        return;
      }
        
      sc.stopAsync();
    }

    // async
    void goto_pos(int32_t position) 
    {
      stop_sw = (position < s.getPosition()) ? pin_sw1 : pin_sw2;
      s.setMaxSpeed(motor_speed);
      s.setAcceleration(motor_speed);
      s.setTargetAbs(position);
      sc.moveAsync(s);
    }

    // async
    void stop_and_goto_pos(int32_t position) {
      pending_goto = true;
      pending_pos = position;
      stop();
    }

    // sync
    void home()
    {
      if (!sw1_hit()) {
        rotate(false, homing_speed, homing_accel);
        while (!sw1_hit());
      }
      s.setPosition(0);
      stop(true);
    }

    // sync
    int32_t find_limit()
    {
      stop(true);
      if (sw2_hit()) {
        return s.getPosition();
      }
      rotate(true, homing_speed, homing_accel);
      while (!sw2_hit());
      int32_t ret = s.getPosition();
      stop(true);
      return ret;
    }

    void update()
    {
      if (!rc.isRunning() && pending_goto) {
        pending_goto = false;
        goto_pos(pending_pos);
      }
      if (rc.isRunning() || sc.isRunning()) {
        if (stop_sw == pin_sw1 && sw1_hit() ){
          s.setPosition(0);
          stop(true);
        }
        if (stop_sw == pin_sw2 && sw2_hit()) {
          stop(true);
        }
      }
    }
};

class Door : public MotorAndSwitches
{
  public:
    bool calibrated;
    int32_t closed_pos;
  
    Door(uint8_t pin_pulse, uint8_t pin_dir, uint8_t pin_sw1, uint8_t pin_sw2, RotateControl& rc)
      : MotorAndSwitches(pin_pulse, pin_dir, pin_sw1, pin_sw2, rc)
    {
      calibrated = false;
      closed_pos = 0;
      motor_speed = DOOR_SPEED;
      motor_accel = DOOR_ACCEL;
    }

    void calibrate()
    {
      home();
      closed_pos = find_limit();
      calibrated = true;
    }

    void open()
    {
      stop_and_goto_pos(0);
    }

    void close()
    {
      stop_and_goto_pos(closed_pos);
    }
};



class Floor : public MotorAndSwitches
{  
  public:
    bool calibrated;

    Floor(uint8_t pin_pulse, uint8_t pin_dir, uint8_t pin_sw1, uint8_t pin_sw2, RotateControl& rc)
      : MotorAndSwitches(pin_pulse, pin_dir, pin_sw1, pin_sw2, rc)
    {
      calibrated = false;
      motor_speed = FLOOR_SPEED;
      motor_accel = FLOOR_ACCEL;
    }

    // blocking
    void calibrate()
    {
      stop(true);
      home();
      calibrated = true;
    }

};

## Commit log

2019-10-31 elevator motherboard wip
    [elevator-motherboard-revA.brd, elevator-motherboard-revA.sch]
2019-11-01 motherboard schematic is done
    [elevator-motherboard-revA.brd, elevator-motherboard-revA.sch]
2019-11-01 better placement
    [elevator-motherboard-revA.brd, elevator-motherboard-revA.sch]
2019-11-01 Done with routing
    [elevator-motherboard-revA.brd, elevator-motherboard-revA.sch]
2019-11-01 Added silkscreen
    [elevator-motherboard-revA.brd]
2019-11-05 Added initial code, renamed to motherboard
    [elevator-motherboard-revA.brd, elevator-motherboard-revA.sch]
2019-11-05 Rev B
    [elevator-motherboard-revB.brd, elevator-motherboard-revB.sch]
2019-11-06 Adding IO panel schematic and layout, missing silkscreen
    [elevator_iopanel_revA.brd, elevator_iopanel_revA.sch]
2019-11-06 Arduino uno simple motor test
2019-11-06 Cleaned up arduino code a bit
2019-11-07 Added LEDs for power rails, silkscreen. sent to fab
    [elevator_iopanel_revA.brd, elevator_iopanel_revA.sch]
2019-11-22 stop the doors when switches hit
2019-11-22 Added UI and some state fixes
    [elevator.ino]
2019-11-23 Call button shouldn't hijack the elevator
2019-11-27 Added some initial addressable LED code - wasn't used

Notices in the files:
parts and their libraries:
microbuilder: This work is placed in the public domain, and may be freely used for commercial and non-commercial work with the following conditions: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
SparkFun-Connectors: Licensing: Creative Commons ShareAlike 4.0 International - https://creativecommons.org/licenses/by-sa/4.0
